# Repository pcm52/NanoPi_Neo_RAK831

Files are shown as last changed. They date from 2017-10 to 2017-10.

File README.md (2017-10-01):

# NanoPi_Neo_RAK831
PCB to connect RAK831 to a NanoPi Neo

Interface has the following:
- optional Ublox GPS module with 1 PPS output to RAK831
- optional USB interface to allow easy configuration of GPS
- optional 128x32 i2c OLED display (at address 3C) 
- optional BMP280/BME280 temp/pressure/humidity sensor
- optional i2c header

More info here:

pcm52.com/2017/10/01/lorawan-gateway/

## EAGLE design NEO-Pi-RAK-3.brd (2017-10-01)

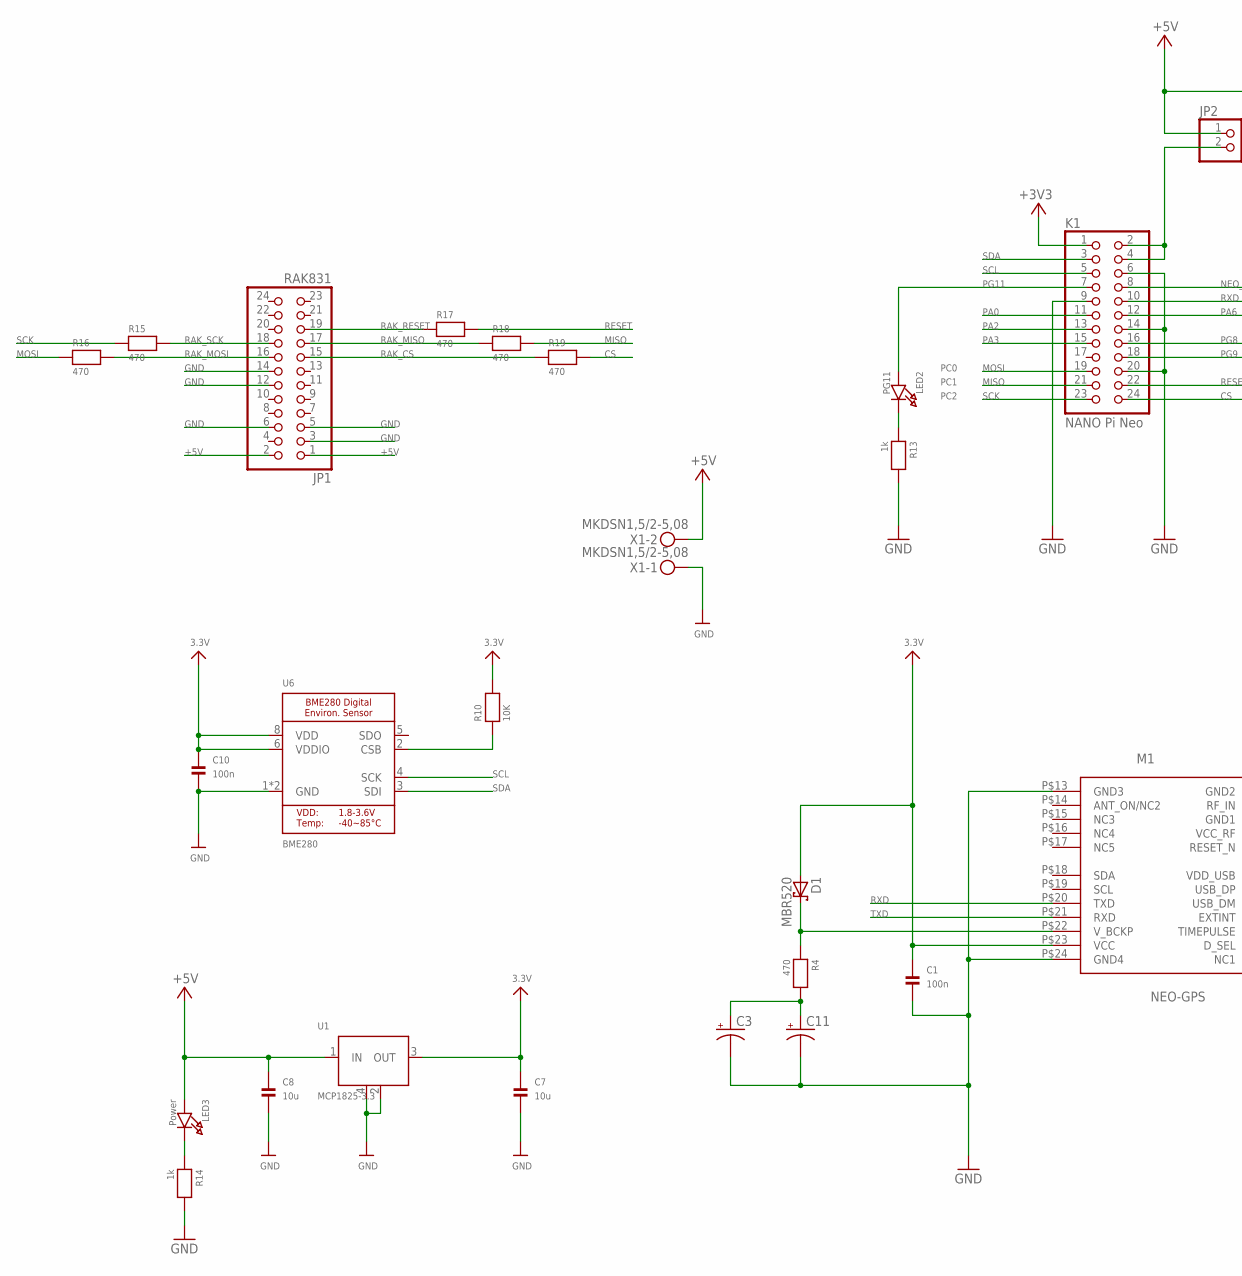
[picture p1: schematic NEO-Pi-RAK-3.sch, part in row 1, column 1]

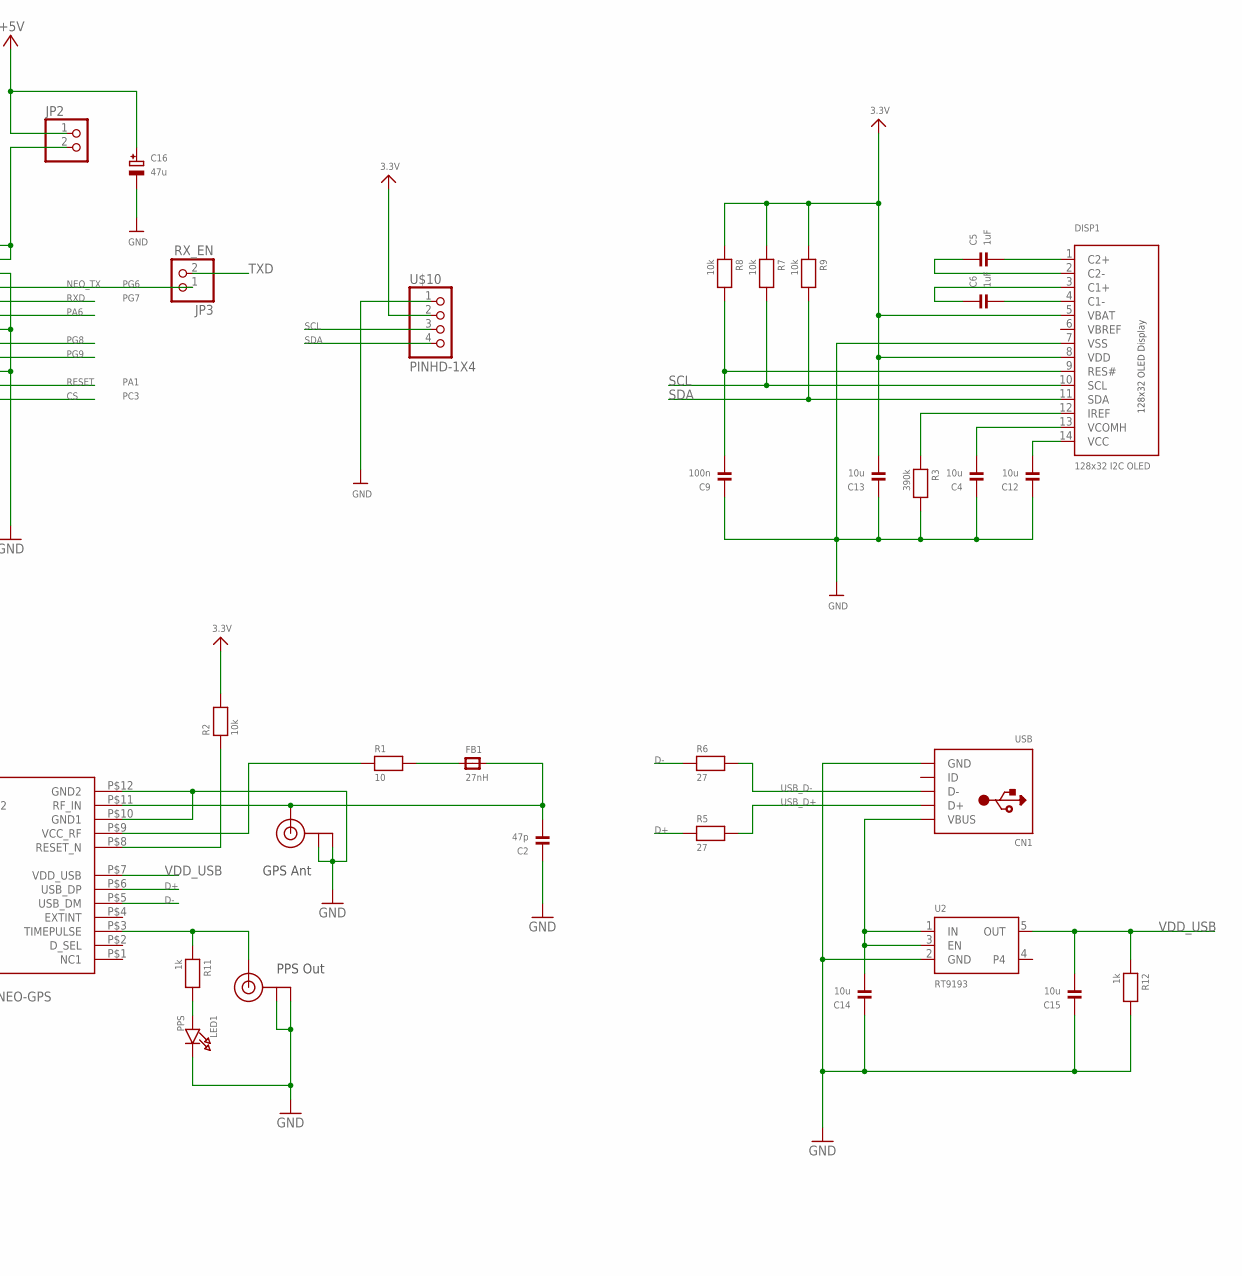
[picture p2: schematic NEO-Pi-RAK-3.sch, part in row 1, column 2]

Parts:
C1, C9, C10: 100n; 0805
C2: 47p; 0805
C3: SUPERCAP; 414-VA5R
C4, C7, C8, C12, C13, C14, C15: 10u; 0805
C5, C6: 1uF; 0805
C11: SUPERCAP
C16: 47u; EIA3528-21/B-R
CN1: USB; USB-MINIB
D1: MBR520; SOD123
DISP1: 128x32 I2C OLED; 0.91-128X32-OLED-I2C
FB1: 27nH; 0805
JP1: RAK831; 2X12
JP2: PINHD-1X2; 1X02
JP3: RX_EN; 1X02
K1: NANO Pi Neo; 2X12
LED1: PPS; CHIPLED_0805
LED2: PG11; CHIPLED_0805
LED3: Power; CHIPLED_0805
M1: NEO-GPS; NEO_GPS
R1: 10; 0805
R2, R7, R8, R9: 10k; 0805
R3: 390k; 0805
R4, R15, R16, R17, R18, R19: 470; 0805
R5, R6: 27; 0805
R10: 10K; 0805
R11, R12, R13, R14: 1k; 0805
U1: MCP1825-3.3; UA78M05
U2: RT9193; SOT23-5
U6: BME280
U$1, U$2: U.FL
U$10: PINHD-1X4; 1X04-BIG
X1: MKDSN1,5/2-5,08

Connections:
3.3V: C1.1, C7.1, C10.1, C13.2, D1.A, DISP1.5 (VBAT), DISP1.8 (VDD), M1.P$23 (VCC), R2.2, R7.1, R8.1, R9.1, R10.2, U1.3 (OUT), U6.6 (VDDIO), U6.8 (VDD), U$10.2
+3V3: K1.1
+5V: C8.1, C16.+, JP1.1, JP1.2, JP2.1, LED3.A, U1.1 (IN), X1.2
CS: K1.24, R19.2
D+: M1.P$6 (USB_DP), R5.1
D-: M1.P$5 (USB_DM), R6.1
GND: C1.2, C2.1, C3.-, C4.1, C7.2, C8.2, C9.1, C10.2, C11.P$2 (-), C12.1, C13.1, C14.1, C15.1, C16.-, CN1.GND, DISP1.7 (VSS), JP1.3, JP1.5, JP1.6, JP1.12, JP1.14, K1.6, K1.9, K1.14, K1.20, LED1.C, M1.P$10 (GND1), M1.P$12 (GND2), M1.P$13 (GND3), M1.P$24 (GND4), R3.2, R12.2, R13.2, R14.2, U1.2 (COMMON1), U1.4 (COMMON2), U2.2 (GND), U6.1 (GND), U6.7 (GND), U$1.P$1 (GND), U$1.P$2 (GND), U$2.P$1 (GND), U$2.P$2 (GND), U$10.1, X1.1
MISO: K1.21, R18.2
MOSI: K1.19, R16.1
unnamed: JP2.2, K1.2, K1.4
unnamed: M1.P$3 (TIMEPULSE), R11.1, U$2.P$3 (SIGNAL)
unnamed: C2.2, FB1.2, M1.P$11 (RF_IN), U$1.P$3 (SIGNAL)
unnamed: FB1.1, R1.2
unnamed: C12.2, DISP1.14 (VCC)
unnamed: M1.P$9 (VCC_RF), R1.1
unnamed: M1.P$8 (RESET_N), R2.1
unnamed: D1.C, M1.P$22 (V_BCKP), R4.1
unnamed: C3.+, C11.P$1 (+), R4.2
unnamed: C4.2, DISP1.13 (VCOMH)
unnamed: LED1.A, R11.2
unnamed: C5.2, DISP1.1 (C2+)
unnamed: C6.2, DISP1.4 (C1-)
unnamed: C6.1, DISP1.3 (C1+)
unnamed: C5.1, DISP1.2 (C2-)
unnamed: C14.2, CN1.VBUS, U2.1 (IN), U2.3 (EN)
unnamed: DISP1.12 (IREF), R3.1
unnamed: LED3.C, R14.1
unnamed: R10.1, U6.2 (CSB)
unnamed: LED2.C, R13.1
NEO_TX: JP3.1, K1.8
PA0: K1.11
PA2: K1.13
PA3: K1.15
PA6: K1.12
PG8: K1.16
PG9: K1.18
PG11: K1.7, LED2.A
RAK_CS: JP1.15, R19.1
RAK_MISO: JP1.17, R18.1
RAK_MOSI: JP1.16, R16.2
RAK_RESET: JP1.19, R17.1
RAK_SCK: JP1.18, R15.2
RESET: K1.22, R17.2
RST_OLED: C9.2, DISP1.9 (RES#), R8.2
RXD: K1.10, M1.P$20 (TXD)
SCK: K1.23, R15.1
SCL: DISP1.10 (SCL), K1.5, R7.2, U6.4 (SCK), U$10.3
SDA: DISP1.11 (SDA), K1.3, R9.2, U6.3 (SDI), U$10.4
TXD: JP3.2, M1.P$21 (RXD)
USB_D+: CN1.D+, R5.2
USB_D-: CN1.D-, R6.2
VBREF: DISP1.6 (VBREF)
VDD_USB: C15.2, M1.P$7 (VDD_USB), R12.1, U2.5 (OUT)

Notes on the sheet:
PA1
PC3
PC0
PC1
PC2
PG6
PG7
GPS Ant
PPS Out

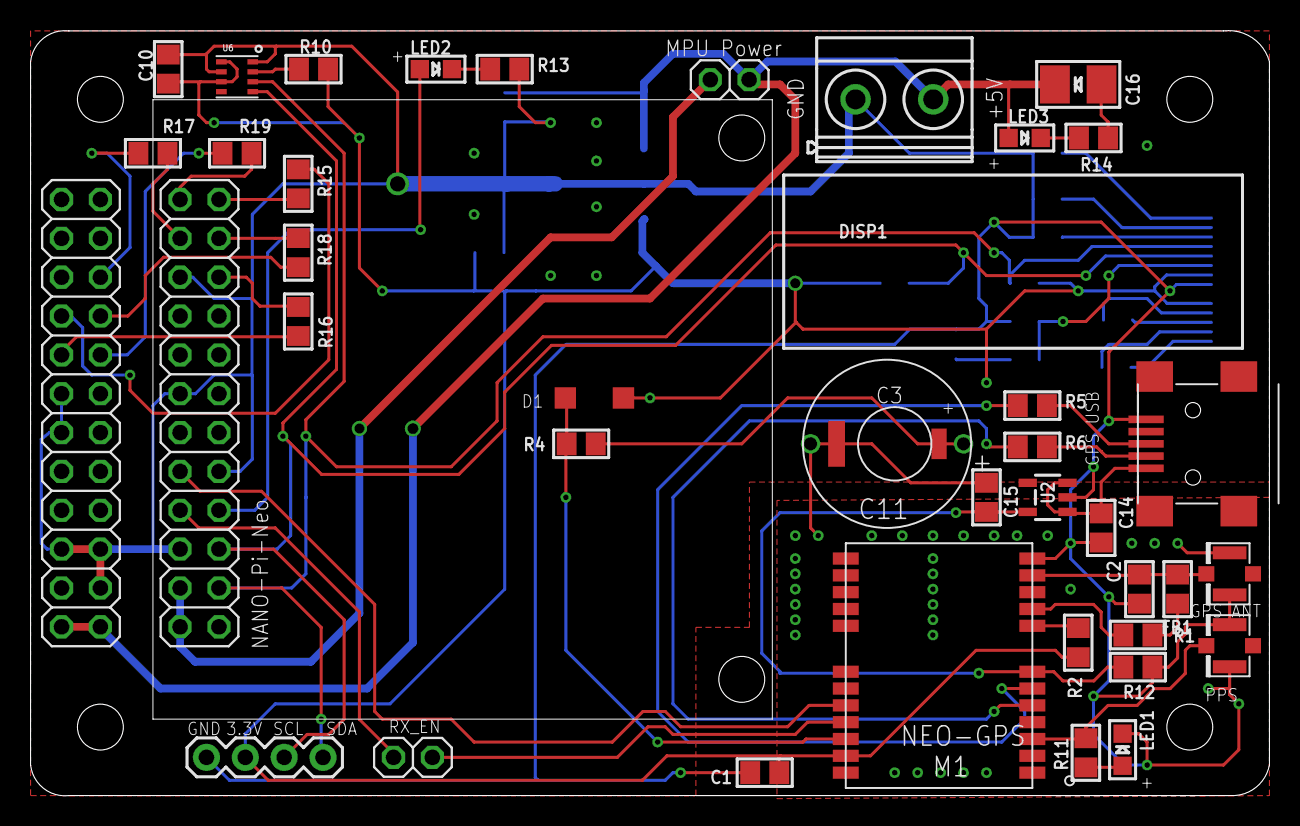
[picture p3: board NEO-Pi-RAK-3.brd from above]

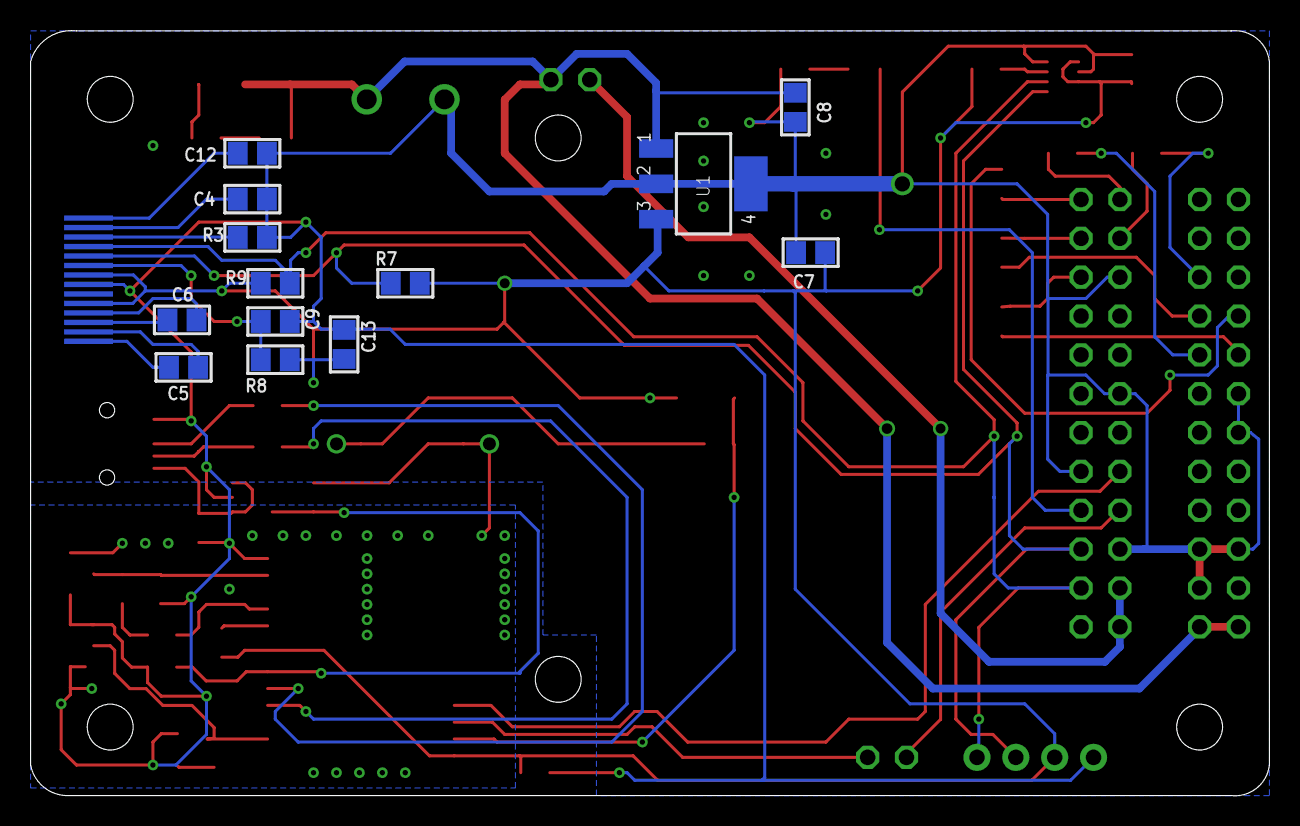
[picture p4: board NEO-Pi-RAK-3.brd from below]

Board: 2 copper layers, 81.0 x 50.0 mm, 54 parts (13 on the bottom side), 45 nets.

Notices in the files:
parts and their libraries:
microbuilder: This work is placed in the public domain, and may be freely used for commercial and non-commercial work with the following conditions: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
